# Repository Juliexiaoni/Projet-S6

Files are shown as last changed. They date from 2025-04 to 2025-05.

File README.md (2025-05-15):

# Projet-S6
## Objectif:

Horloge tournante à persistence rétinienne

Simuler une horloge analogique dynamique
## Planning prévisionnel

### Semaine 1 : Etude et conception

Définir les objectif (taille, résolution, affichage prévu):

- Affichage avec les 3 aiguilles

Choix des composantes (STM32, moteur, alimentation)  
Réaliser schéma électronique et mécanique   
Déterminer la fréquence de rotation optimale

### Semaine 2 : Première prototypage 

Une barrette de douze leds et le code sur le sTM32  
Branchement et alimentation puis …  
Pour faire une test avec l’ancien plaquette/moteur du projet

### Semaine 3 : Achats et fabrication du support

Acheter les composants et matériaux (Moteurs, Leds, Microprocesseur…)  
Concevoir le support du bras rotatif (PCB)  
Monter le moteur et le bras sur une base stable  
Ajouter un contrepoids pour limiter les vibrations

### Semaine 4-5 : Assemblage électronique 

### Semaine 6-7 : Programmation et Tests

### Semaine 8 : Optimisation et finalisation

## Cahier des charges

### Différentes étapes:
1. Dimensionner l’horloge 
2. développement du code en C
3. Realisation du PCB
4. Choix moteur (MCC) + axe de rotation
5. Choix des leds (blanches et rouges) → pas de driver LED
6. Choix du microcontroleur/microprocesseur 

### Matériel
1. Stm32F303K8T6
2. Moteurs https://fr.transmotec.com/product/HD3SFN-6040-CC/
3. Régulateur de tension 
4. Batterie 9V

### Tableau 

| Fonction | Critère | Niveau | Commentaires  | Qui s’en charge principalement | Avancement |
| :---- | :---- | :---- | :---- | :---- | :----|
| Mouvement le la barre de LED | Fréquence de rotation ωLED | \< 20 ms soit  \>50 Hz |  |  |  |
|  | Contact de la barre des LED’s au support | Fixe. Aucun angle de roulis ou tangage  |  |  | fait |
|  | Axe de rotation | l’axe x; mouvement plan |  |  | fait |
|  | Fixation de la barre au support  | Liaison cylindre fixé |  |  |  |
|  | Alimentation de la barre | 3.3V → pile 9V | L'entrée peut supporter jusqu’à 12 V |  |  |
|  | Codage des LED’s | Langage C valable pour STM32 |  | Julie |  |
| Moteur | Fixation du moteur au support  |  |  |  |  |
|  | Transmission ωmoteur à ωLED  |  | Idéalement aucune pertes |  | fait |
|  | Vitesse de rotation | Constante, \>3000 rpm |  |  |  |  |
| Donner l’heure  | Synchronisation des mouvements des aiguilles en fonction de l’heure  | À la seconde près  OU si on aime les défis à la ms près | Existe des modules dont le RTC | Laure |  |
|  | Affiche des aiguilles | 3 aiguilles  |  |  |  |  |
| Confort visuel | Fréquence de rotation assez élevée pour ne plus avoir de scintillement  | \>50Hz |  |  |  |
|  | Intensité des LEDs  | Fixe, indice UGR\<18 | C’est du superflu |  |  |
| Dimensions  |  | À ajuster en fonction des autres élements | Optimiser l’espace un maximum |  |  |

## Deroulé des séances

### Récapitulatif de la séance 1
1. Dimension de notre horloge (20 cm de diamètre; 3 colonnes de 12 leds en // codée individuellement et de couleur différentes)
2. choix de l'affichage de notre horloge (3 aiguilles (s:10, m:9, h:5) + indice pour se repérer sur le cadran codé sur 1 ou 2 leds sur l'aiguille de heure) #idéalement et si on a le temps 
3. micro controleur STM32Nucleo : Stm32F303K8T6
4. Determination de la fréquence (65 Hz)
5. Recherche d'un moteur MCC adéquat
6. Debut des test , notamment allumer des leds

### Objectif de la séance 2
1. realiser un premier test de frequence
2. essayer de coder une barre de LED entierement allumées et la faire tourner jusqu'à qu'il n'y a plus de scitimment

### Récapitulatif de la séance 2
1. Conception du premier prototype de PCB
2. Retour sur l'idée des trois colonnes de leds. Juste 1 de 11 LEDs => commande séparée de chacune des LEDs
3. Début de l'attribution des pattes du microcontrolleur + début du code
4. Premier essai de faire fonctionner le moteur --> Pas concluant: desaxé et inertie trop importante. 
    
#### Pour recevoir l'heure en temps réel il faut un module RTC 

### Objectifs de la séance 3
1. Trouver le bon module RTC compatible avec le micocontroleur choisi <-- on a plutôt chercher à comprendre le module RTC
2. Réaliser un premier PCB sur Kicad
3. Finaliser le code d'au moins une LED
4. Realiser un premier test en faisant touner une barre de LEDs/1 LED allumée jusqu'à plus aucun scintillemment avec le moteur

### Récapitulatif de la séance 3
1. Test avec les petits moteurs
2. Changement de STM32F303K8 --> STM32G431KBT6
3. Début du schématic de Kicad avec la STM 32 adaptée

### Objectifs de la séance 4
1. Avancer sur le prototypes des LED
2. Avancer sur le code
3. Continuer le PCB

### Récapitulatif de la séance 4
1. Prototype de la barre des LED fini
2. Premier essaie du système {moteur + barre de LED} => tourne très bien à ~ 6V mais beaucoups de vibrations
4. Test du code : problème d'IDE
5. Poursuite du schématic de Kicad 

### Objectifs de la séance 5
1. Finaliser le code pour qu'il soit fonctionnel
2. Avoir le upport pour le moteur
3. taille des trous de fixation du moteur
4. Finalisation du PCB
5. Réaliser un premier test avec les LED allumés (prototype complet)

### Recapitulatid seance 5

### Objectif séance 6

### Recapitulatif séance 6

### Objectifs séance 7

### Récapitulatif séance 8
 1. PCB entièrement fini sur Kicad
 2. test de la vitesse de rotation du moteur choisi → plus faible qu'escompté mais suffisant pour voir une image (test du laser rouge)
 3. changeant de choix d'alimentation du microcontrolleur  (2 cellules de 3,5V )
 4. Avancées du code:

### Objectif de la dernière séance (9)
 1. soudage du PCB
 2. montage global
 3. Test
 + Si le temps cache pour la pile

### Séance 9
**Problème: pas de PCB car commande trop tard**
donc programme prévue: faire le prototypage complet
## Ressources 
https://m.youtube.com/watch?v=QOkp9amAs68
https://wiki.st.com/stm32mcu/wiki/Getting_started_with_RTC

### Contacts

kessal@ensea.fr

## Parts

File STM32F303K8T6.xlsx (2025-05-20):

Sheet: List
List of MCUs selection: 1 items. Database version: 2025-04-23
Favorite | Commercial Part No | Part No | Reference | Marketing Status | Unit Price for 10kU (US$) | Board | Package | Flash | RAM | I/O | Frequency
 | STM32F303K8T6 | STM32F303K8 | STM32F303K8Tx | Active | 2.5814 | NUCLEO-F303K8 | LQFP 32 7x7x1.4 mm | 64 kBytes | 16 kBytes | 25 | 72 MHz

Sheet: Filters
List of MCUs selection: 1 items. Database version: 2025-04-23
Filter | Value | User Selected
Name | STM32F303K8T6 | Y
Segment | STM32 Mainstream MCUs | Y
Series | STM32F3 | Y
Line | STM32F303 | Y
MarketingStatus | Active | N
Package | LQFP 32 7x7x1.4 mm | N
Core | Arm Cortex-M4 | N
DualBankFlash | No | N
TimerFunction | Dual Watchdog, IR timer, RTC, SysTick | N
IPCC | No | N
Price | 2.5814 to 2.5814 | N
PinCount | 32 to 32 | N
Freq | 72 to 72 | N
CoproFreq | 0 to 0 | N
Flash | 64 to 64 | N
Eeprom | 0 to 0 | N
RamTotal | 16 to 16 | N
Ram | 16 to 16 | N
CcmRam | 0 to 0 | N
SRAM | 0 to 0 | N
TimerTotal | 8 to 8 | N
Timer8 | 0 to 0 | N
Timer16 | 7 to 7 | N
Timer32 | 1 to 1 | N
LpTimer | 0 to 0 | N
AmcTimer | 0 to 0 | N
ADCTotal | 2 to 2 | N
ADC10Channel | 0 to 0 | N
ADC12 | 2 to 2 | N
ADC12Channel | 9 to 9 | N
ADC12ChannelSTM8 | 0 to 0 | N
ADC14 | 0 to 0 | N
ADC14Channel | 0 to 0 | N
ADC16 | 0 to 0 | N
ADC16Channel | 0 to 0 | N
DAC12 | 3 to 3 | N
COMP | 2 to 2 | N
OPAMP | 1 to 1 | N
CANTotal | 2 to 2 | N
CAN | 1 to 1 | N
CAN2 | 1 to 1 | N
FDCAN | 0 to 0 | N
I2CTotal | 1 to 1 | N
I2C | 1 to 1 | N
FMPI2C | 0 to 0 | N
I3C | 0 to 0 | N
SPITotal | 3 to 3 | N
SPI | 1 to 1 | N
I2S | 0 to 0 | N
SAI | 0 to 0 | N
UARTTotal | 2 to 2 | N
USART | 2 to 2 | N
UART | 0 to 0 | N
LINUART | 0 to 0 | N
LPUART | 0 to 0 | N
EthernetPort | 0 to 0 | N
USB2 | 0 to 0 | N
USBHHS | 0 to 0 | N
USBDRDFS | 0 to 0 | N
UCPD | 0 to 0 | N
QUADSPITotal | 0 to 0 | N
QUADSPI | 0 to 0 | N
OCTOSPI | 0 to 0 | N
DFSDM | 0 to 0 | N
SDMMC | 0 to 0 | N
IO | 25 to 25 | N
VoltageLow | 200 to 200 | N
VoltageHigh | 360 to 360 | N
CurrentLow | 140 to 140 | N
CurrentRun | 35300 to 35300 | N
CurrentStandby | 0 to 0 | N
RXCurrent | 0 to 0 | N
TXCurrent | 0 to 0 | N
RXSensitivity | 0 to 0 | N
OutputPowerLow | 0 to 0 | N
OutputPowerHigh | 0 to 0 | N
TemperatureLow | -40 to -40 | N
TemperatureHigh | 85 to 85 | N
JunctionTempLow | 0 to 0 | N
JunctionTempHigh | 0 to 0 | N

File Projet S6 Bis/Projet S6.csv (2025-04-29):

Reference | Value | Footprint | Datasheet | Qty | DNP
D1,D2,D3,D4,D5,D6,D7,D8,D9,D10,D11 | LED | LED_SMD:LED_1206_3216Metric_Pad1.42x1.75mm_HandSolder | ~ | 11
J3 | Conn_01x04_Socket | Connector_PinSocket_2.54mm:PinSocket_1x04_P2.54mm_Vertical | ~ | 1
J101 | Conn_01x02 | Connector_JST:JST_XH_S2B-XH-A_1x02_P2.50mm_Horizontal | ~ | 1
Nucleo2 | ~ | Maker_librairy:MODULE_NUCLEO-F303K8 |  | 1
R1,R2,R3,R4,R5,R6,R7,R8,R9,R10,R11 | 220 | Resistor_SMD:R_0805_2012Metric_Pad1.20x1.40mm_HandSolder | ~ | 11

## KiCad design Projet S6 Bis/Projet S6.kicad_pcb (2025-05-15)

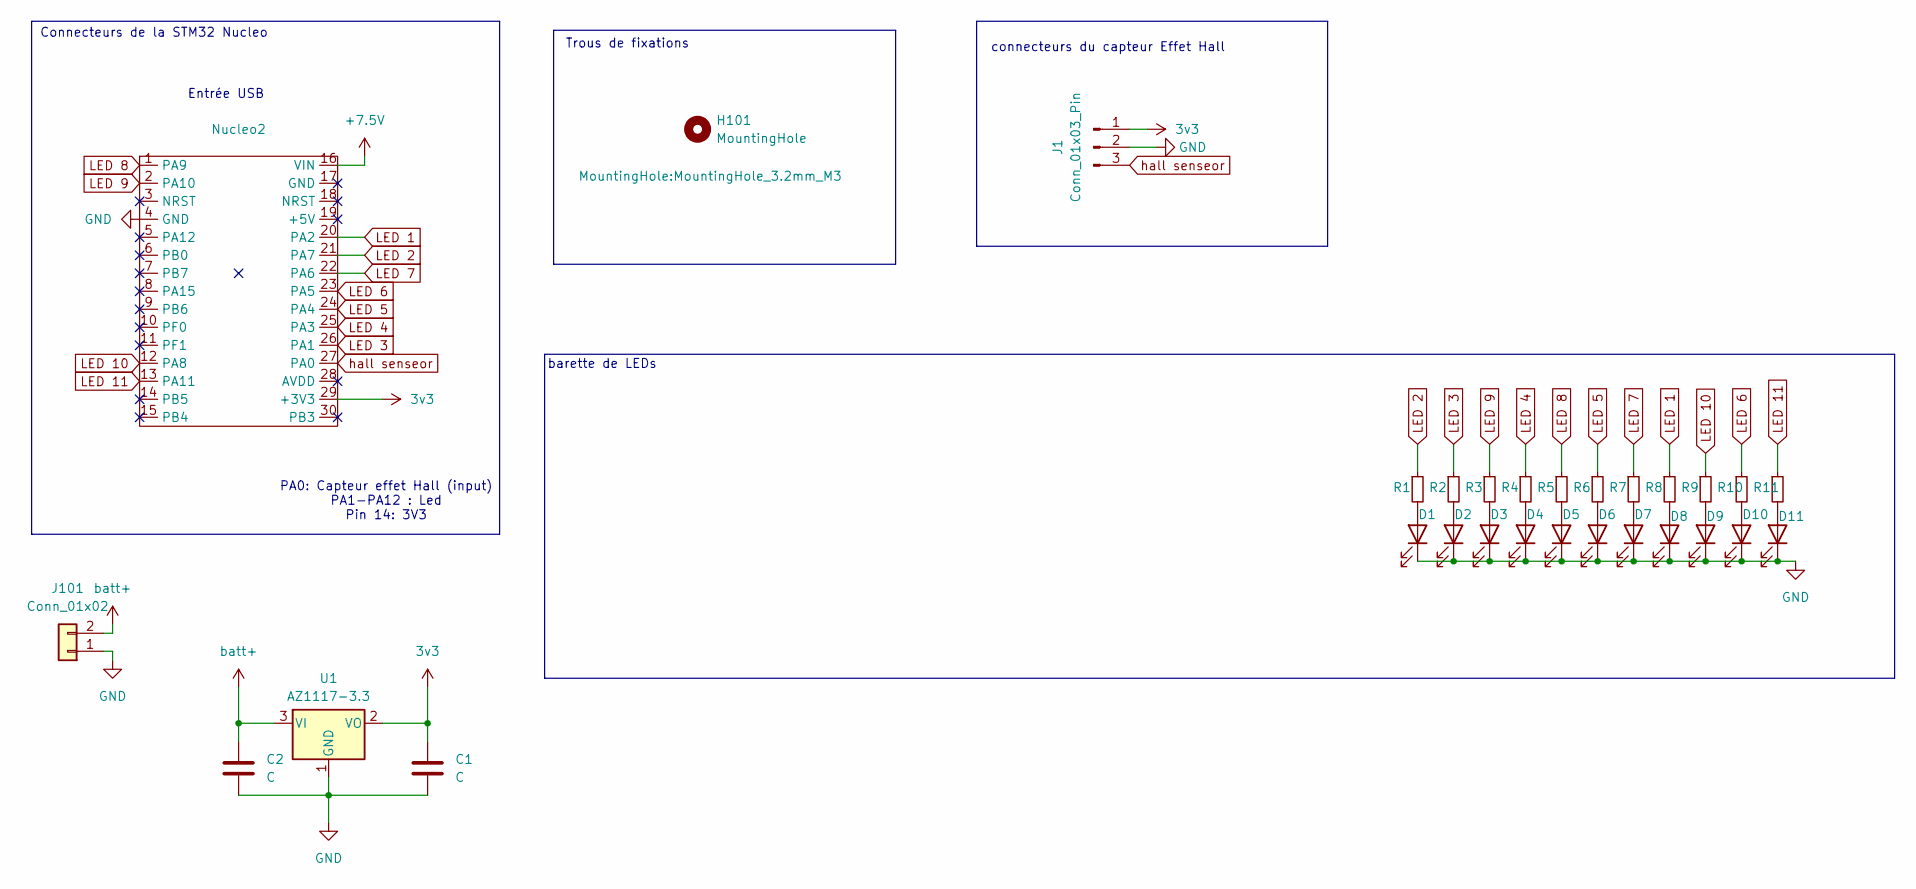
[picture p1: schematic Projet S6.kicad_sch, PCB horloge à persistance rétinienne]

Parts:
C1, C2: C; C_0603_1608Metric_Pad1.08x0.95mm_HandSolder
D1, D2, D3, D4, D5, D6, D7, D8, D9, D10, D11: LED; C_0402_1005Metric_Pad0.74x0.62mm_HandSolder
H101: MountingHole; MountingHole_3.2mm_M3
J1: Conn_01x03_Pin; PinHeader_1x03_P2.54mm_Vertical
J101: Conn_01x02; JST_XH_B2B-XH-AM_1x02_P2.50mm_Vertical
Nucleo2: Arduino_Nano
R1, R2, R3, R4, R5, R6, R7, R8, R9, R10, R11: 220; R_0805_2012Metric_Pad1.20x1.40mm_HandSolder
U1: AZ1117-3.3; SOT-223-3_TabPin2

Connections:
3v3: C1.1, J1.1, Nucleo2.29 (+3V3), U1.2 (VO)
+7.5V: Nucleo2.16 (VIN)
GND: C1.2, C2.2, D1.1 (K), D2.1 (K), D3.1 (K), D4.1 (K), D5.1 (K), D6.1 (K), D7.1 (K), D8.1 (K), D9.1 (K), D10.1 (K), D11.1 (K), J1.2, J101.1, Nucleo2.4 (GND), U1.1 (GND)
LED 1: Nucleo2.20 (PA2), R8.1
LED 2: Nucleo2.21 (PA7), R1.1
LED 3: Nucleo2.26 (PA1), R2.1
LED 4: Nucleo2.25 (PA3), R4.1
LED 5: Nucleo2.24 (PA4), R6.1
LED 6: Nucleo2.23 (PA5), R10.1
LED 7: Nucleo2.22 (PA6), R7.1
LED 8: Nucleo2.1 (PA9), R5.1
LED 9: Nucleo2.2 (PA10), R3.1
LED 10: Nucleo2.12 (PA8), R9.1
LED 11: Nucleo2.13 (PA11), R11.1
unnamed: D1.2 (A), R1.2
unnamed: D2.2 (A), R2.2
unnamed: D3.2 (A), R3.2
unnamed: D4.2 (A), R4.2
unnamed: D5.2 (A), R5.2
unnamed: D6.2 (A), R6.2
unnamed: D7.2 (A), R7.2
unnamed: D8.2 (A), R8.2
unnamed: D9.2 (A), R9.2
unnamed: D10.2 (A), R10.2
unnamed: D11.2 (A), R11.2
batt+: C2.1, J101.2, U1.3 (VI)
hall senseor: J1.3, Nucleo2.27 (PA0)

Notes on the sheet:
barette de LEDs
connecteurs du capteur Effet Hall
Entrée USB
PA0: Capteur effet Hall (input) PA1-PA12 : Led Pin 14: 3V3
Trous de fixations
Connecteurs de la STM32 Nucleo

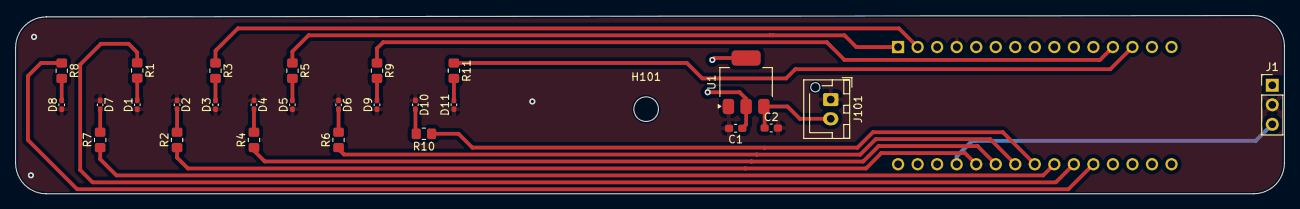
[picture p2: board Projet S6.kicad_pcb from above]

Board: 2 copper layers, 165.0 x 23.2 mm, 29 parts (1 on the bottom side), 26 nets.

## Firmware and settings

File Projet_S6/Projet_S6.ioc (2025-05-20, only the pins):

Mcu.UserName=STM32F303K8Tx
PA0.Signal=GPIO_Output
PA1.Signal=GPIO_Output
PA10.Signal=GPIO_Output
PA13.GPIO_Label=SWDIO
PA13.Signal=SYS_JTMS-SWDIO
PA14.GPIO_Label=SWCLK
PA14.Signal=SYS_JTCK-SWCLK
PA15.GPIO_Label=VCP_RX
PA15.Signal=USART2_RX
PA2.Signal=GPIO_Output
PA3.Signal=GPIO_Output
PA4.Signal=GPIO_Output
PA5.Signal=GPIO_Output
PA6.Signal=GPIO_Output
PA7.Signal=GPIO_Output
PA8.Signal=GPIO_Output
PA9.Signal=GPIO_Output
PB0.Signal=GPIO_Input

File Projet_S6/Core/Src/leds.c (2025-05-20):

/*
 * leds.c
 *
 *  Created on: May 20, 2025
 *      Author: laure
 */

#include "main.h"
#include "stm32f3xx_it.h"
#include "leds.h"


uint16_t LEDS[LED_COUNT] = {
    GPIO_PIN_0, GPIO_PIN_1, GPIO_PIN_2, GPIO_PIN_3, GPIO_PIN_4,
    GPIO_PIN_5, GPIO_PIN_6, GPIO_PIN_7, GPIO_PIN_8, GPIO_PIN_9, GPIO_PIN_10};


void set_leds(uint8_t position) {
	HAL_GPIO_WritePin(GPIOA, GPIO_PIN_All, GPIO_PIN_RESET);  // Éteindre toutes les LEDs
	if (position == 0) {  // Position MIDI (PA0 à PA9 allumées + PA10 toujours allumée)
		for (int i = 0; i < 10; i++) {
			HAL_GPIO_WritePin(GPIOA, LEDS[i], GPIO_PIN_SET);
		}
      }
	else {  // Position 15h (PA0 à PA5 allumées + PA10 toujours allumée)
        for (int i = 0; i < 6; i++) {
        	HAL_GPIO_WritePin(GPIOA, LEDS[i], GPIO_PIN_SET);
          }
      }

      // LED 11 (PA10) reste toujours allumée
      HAL_GPIO_WritePin(GPIOA, GPIO_PIN_10, GPIO_PIN_SET);
  }

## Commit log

2025-02-12 Mise à jour de README
2025-04-29 ajout du fichier PCB
    [Projet S6-B_Cu.gbr, Projet S6-B_Mask.gbr, Projet S6-B_Paste.gbr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]
2025-04-29 PBC avec les LED 1206 et sans aucunes erreurs au DRC
    [Projet S6.kicad_pcb]
2025-05-20 Correction du Timer et clignotement des LEDs
    [Projet S6-B_Cu.gbr, Projet S6-B_Mask.gbr, Projet S6-B_Paste.gbr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]
